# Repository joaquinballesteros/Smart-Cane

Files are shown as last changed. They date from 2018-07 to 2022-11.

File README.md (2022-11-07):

# Smart Cane


Smart-cane is an open hardware and open software project created to promoting an active ageing. This project was created on [Integrated Systems Engineering group](www.grupoisis.uma.es/), on Department of Electronic Technology (Málaga University). Nowadays, it is carried out at MDH University at the [Biomedical Engineering group](http://www.es.mdh.se/research-groups/32-Biomedical_Engineering) in collaboration with [Integrated Systems Engineering group](www.grupoisis.uma.es/).

The project is led by [Dr. Ballesteros](https://www.researchgate.net/profile/Joaquin_Ballesteros) and it counts with the help of [M.Sc. Alberto Tudela](https://duma.uma.es/duma/buscador/persona/535571bb-1da1-4cbd-a49a-7b0d61c4cd2d/), [B.Sc. Juan Caro](https://duma.uma.es/duma/buscador/persona/6eeb9474-2ce9-4c46-8f6d-ff7827abb2c9/) and the support of [Prof. Dr. Maria Lindén](http://www.es.mdh.se/staff/114-Maria_Lind__n) and [Prof. Dr. Cristina Urdiales](https://www.researchgate.net/profile/Cristina_Urdiales2).

This project is focused on adding on-board sensors to the cane to monitor users. These sensors should be affordable in order to reduce the cost and to increase the number of end users. Force sensors and hall effect sensors are being testing to measure the weight-bearing and other significant parameters related with an active ageing. The results are been validated in collaboration with the following Senior centres (Centros de participación activa) in Córdoba (Spain): CÓRDOBA II, FUENSANTA – CAÑERO, PONIENTE, LOS NARANJOS.

## Built With
* [Fusion 360](https://www.autodesk.com/products/fusion-360/overview) - The program used to to design the plastic pieces. All these documents have been exported to STEP file extension too. It is an ISO standard exchange format that can be openned by other programs, such as [FreeCAD](https://github.com/FreeCAD/FreeCAD).

* [MBED online compiler](https://os.mbed.com/handbook/mbed-Compiler) - The online program used to to programming the BLE Nano v1 microcontroller. 

* [Android Studio](https://developer.android.com/studio/) - The program to create the mobile software.

## Authors

* **Joaquín Ballesteros** - *Team leader, design and programming* - [joaquinballesteros](https://github.com/joaquinballesteros)
* **Alberto Tudela** - *Electronic and 3D models* - [ajtudela](https://github.com/ajtudela)
* **Juan Caro** - *Electronic and software* - [jrcaro](https://github.com/jrcaro)

Contact: jballesteros@uma.es

## Contributors

* Swedish Knowledge Foundation (KKS) through the research profile [Embedded Sensor Systems for Health at Mälardalen University](https://www.mdh.se/forskning/inriktningar/inbyggda-system/ess-h?l=en_UK), Sweden - [Prof. Dr. Maria Lindén](http://www.es.mdh.se/staff/114-Maria_Lind__n).

* [Plan Propio de la Universidad de Málaga (Proyectos Puente)](https://www.uma.es/servicio-de-investigacion/cms/menu/plan-propio-de-investigacion/?set_language=en) at Málaga University, Spain -  [Prof. Dr. Cristina Urdiales](https://www.researchgate.net/profile/Cristina_Urdiales2).

## License

This project is licensed under the Creative Commons Attribution 4.0 - see the [LICENSE.md](https://github.com/joaquinballesteros/Smart-Cane/blob/master/LICENSE) file for details.

## Acknowledgments

The authors would like to thank to [Ms. Luna Ruiz](http://lunakageyama.blogspot.com/) who greatly assisted every single test.

## Publications
Ballesteros, J., Tudela, A., Caro-Romero, J. R., & Urdiales, C. (2019). Weight-bearing estimation for cane users by using onboard sensors. Sensors, 19(3), 509. [link](https://www.mdpi.com/1424-8220/19/3/509/htm)

Ballesteros, J., Tudela, A., Caro-Romero, J. R., & Urdiales, C. (2019, May). A cane-based low cost sensor to implement attention mechanisms in telecare robots. In 2019 International Conference on Robotics and Automation (ICRA) (pp. 1473-1478). IEEE.[link](https://ieeexplore.ieee.org/document/8794283)

Caro-Romero, J. R., Ballesteros, J., Garcia-Lagos, F., Urdiales, C., & Sandoval, F. (2019, June). A Neural Network for Stance Phase detection in smart cane users. In International Work-Conference on Artificial Neural Networks (pp. 310-321). Springer, Cham.[link](https://link.springer.com/chapter/10.1007/978-3-030-20521-8_26)

Ayala, I., Ballesteros, J., Caro-Romero, J. R., Amor, M., & Fuentes, L. (2019). Self-Adaptation of mHealth Devices: The Case of the Smart Cane Platform. In Multidisciplinary Digital Publishing Institute Proceedings (Vol. 31, No. 1, p. 23).[link](https://www.mdpi.com/2504-3900/31/1/23)

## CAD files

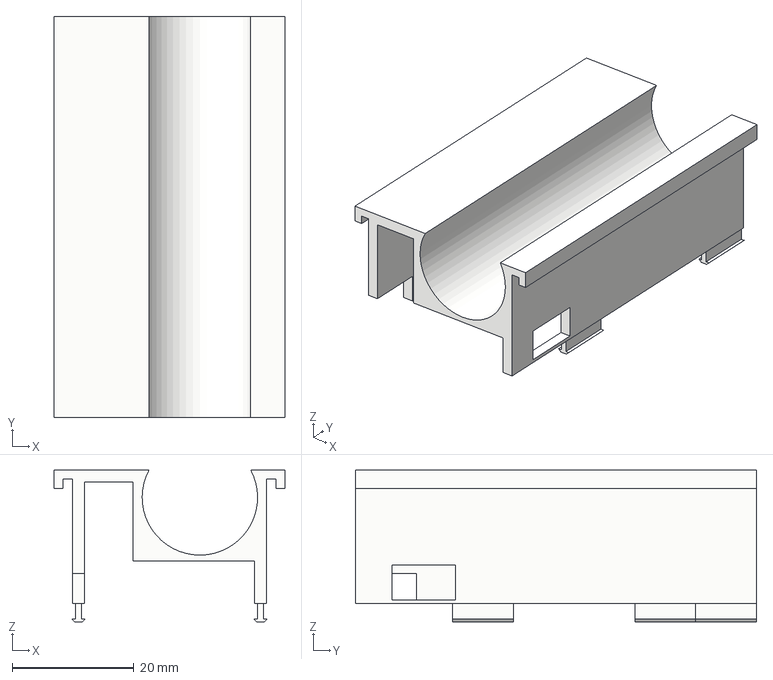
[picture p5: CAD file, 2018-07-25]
CAD/Battery Case/Battery.step
38.0 x 66.0 x 25.0 mm

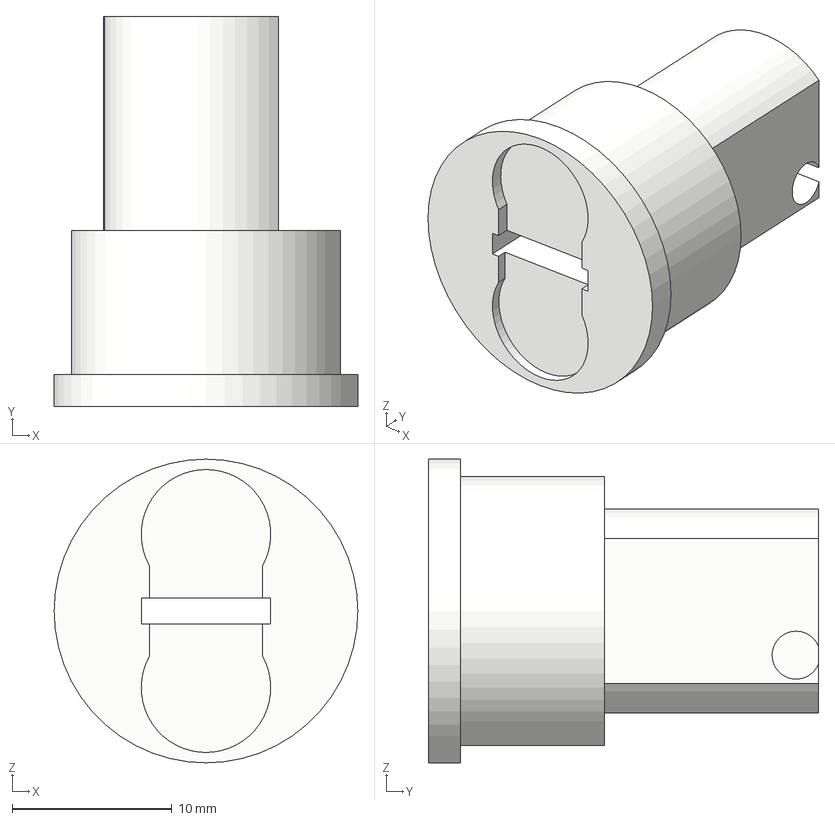
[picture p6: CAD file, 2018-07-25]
CAD/Electronic Case/Interior Sensors.step
19.0 x 24.4 x 19.0 mm

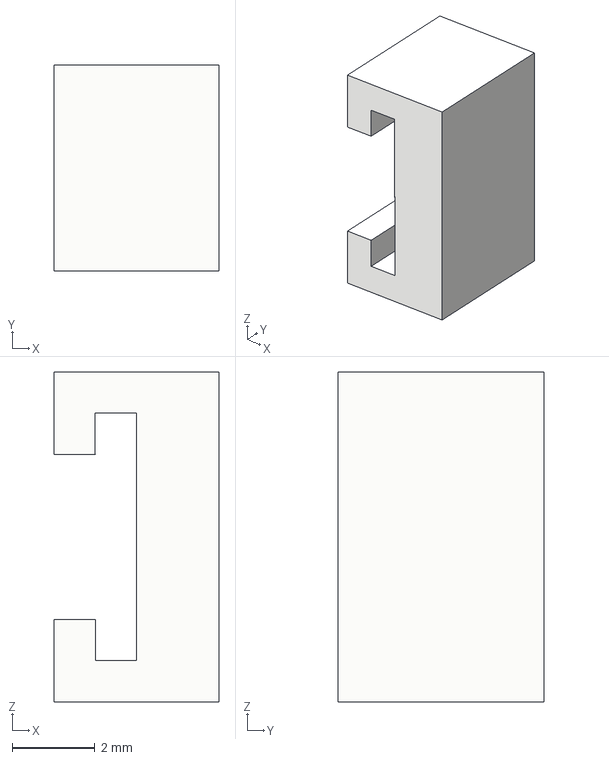
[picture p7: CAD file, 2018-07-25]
CAD/MCU Case/Coupling.step
4.00 x 5.00 x 8.00 mm

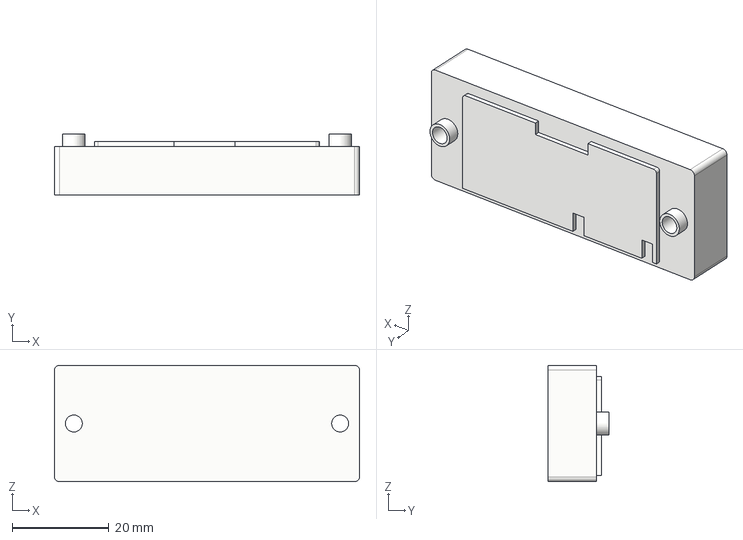
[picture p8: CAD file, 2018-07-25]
CAD/Wall Case/PCB Top.step
63.0 x 12.5 x 24.0 mm

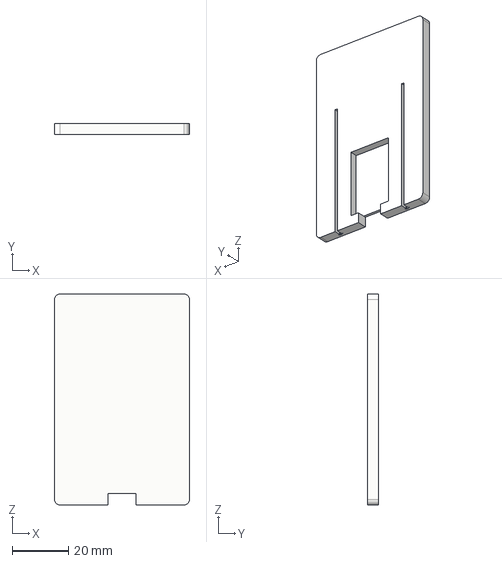
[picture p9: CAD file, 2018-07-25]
CAD/Battery Case/Charger.step
48.0 x 4.00 x 75.0 mm

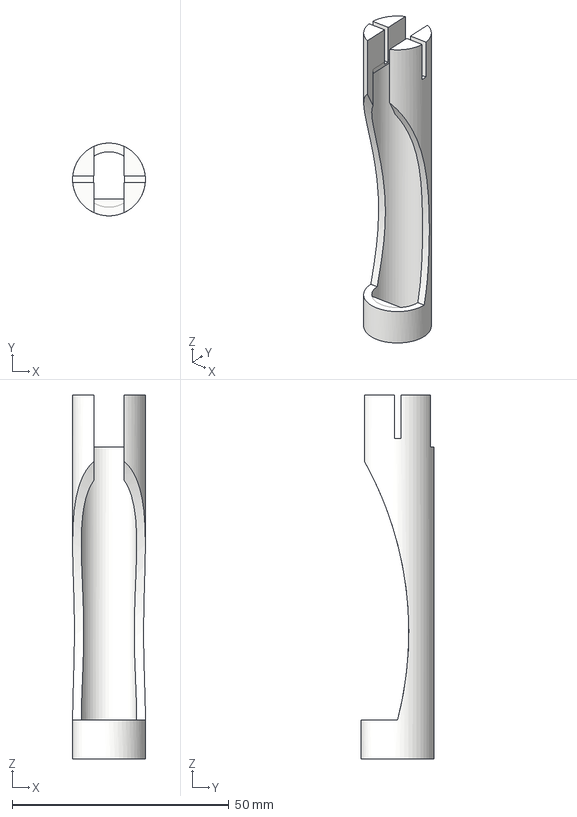
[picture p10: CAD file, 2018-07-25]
CAD/Electronic Case/Board Case.step
16.8 x 16.8 x 84.0 mm

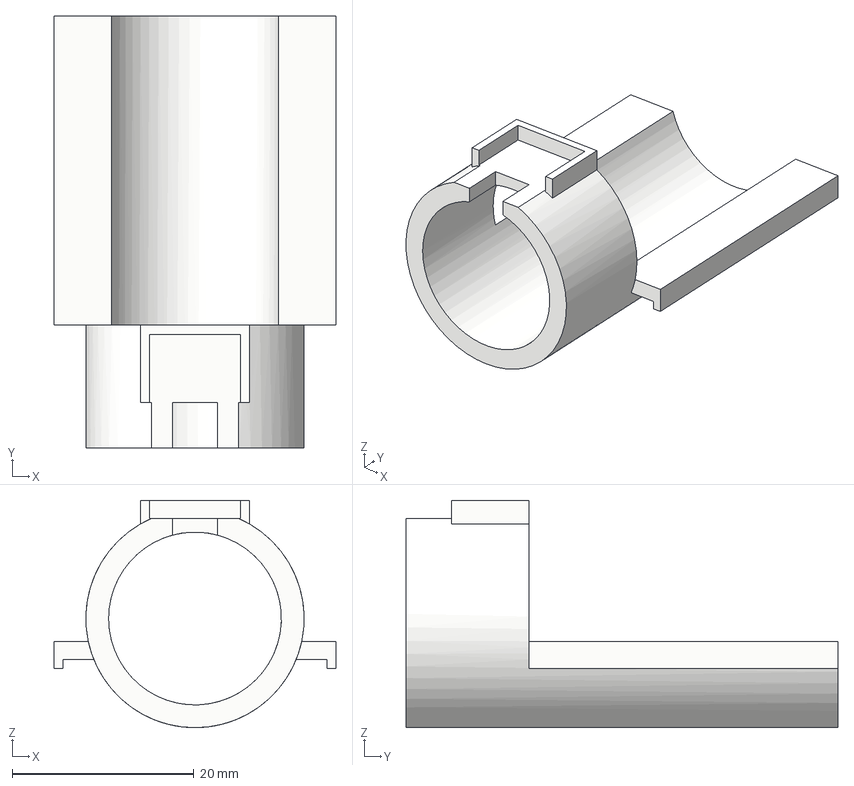
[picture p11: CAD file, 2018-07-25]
CAD/MCU Case/ConectorCase.step
31.0 x 47.5 x 25.0 mm

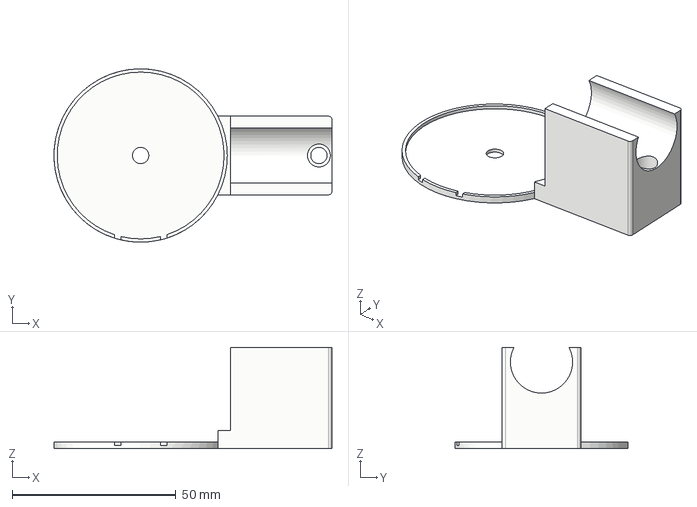
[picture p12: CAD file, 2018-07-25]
CAD/Wall Case/Coil Case.step
85.0 x 53.0 x 31.0 mm

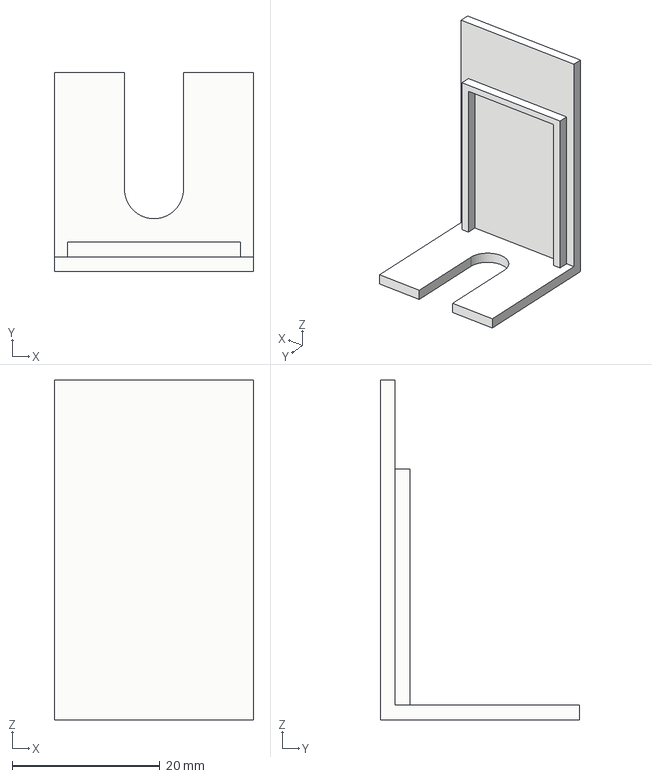
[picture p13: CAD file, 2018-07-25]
CAD/MCU Case/Top.step
27.0 x 27.0 x 46.1 mm

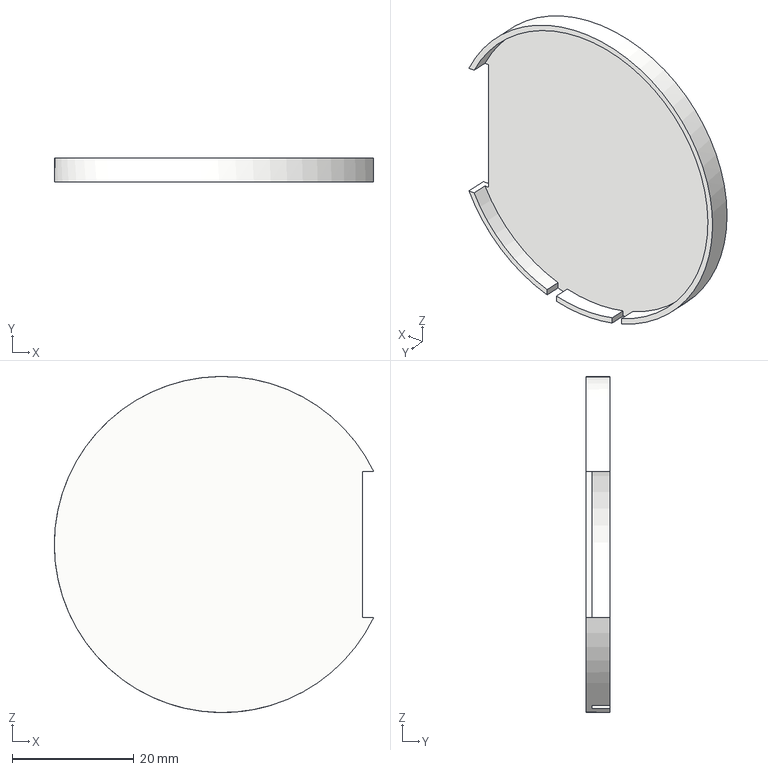
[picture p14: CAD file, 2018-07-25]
CAD/Wall Case/Coil Top.step
52.4 x 4.00 x 55.1 mm

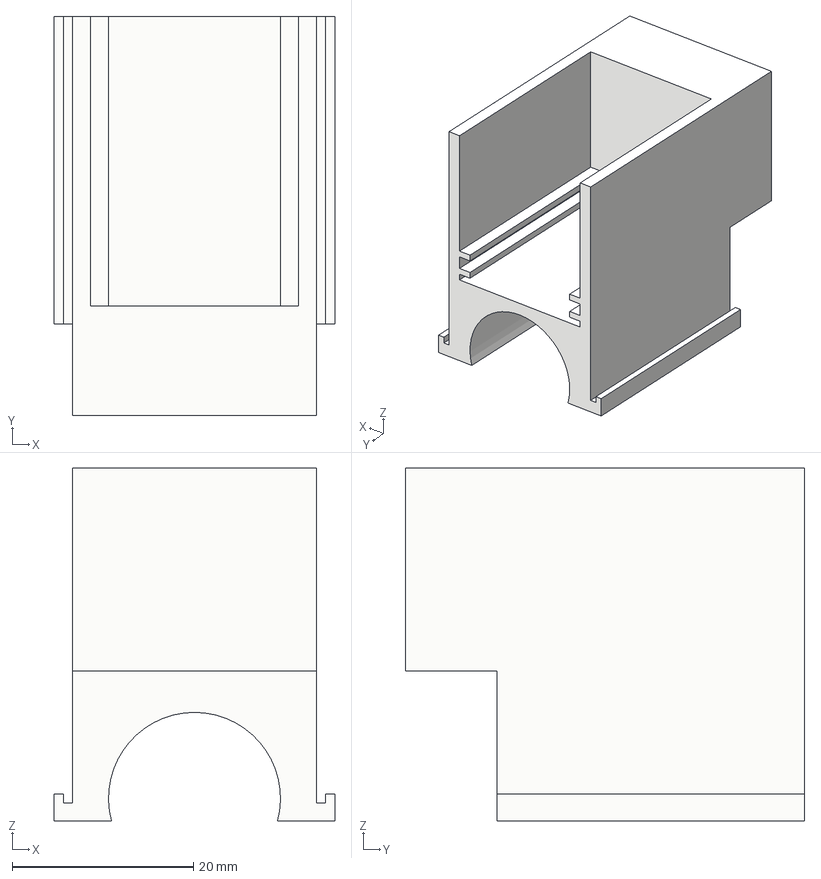
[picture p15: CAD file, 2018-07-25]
CAD/MCU Case/Case.step
31.0 x 44.1 x 39.0 mm

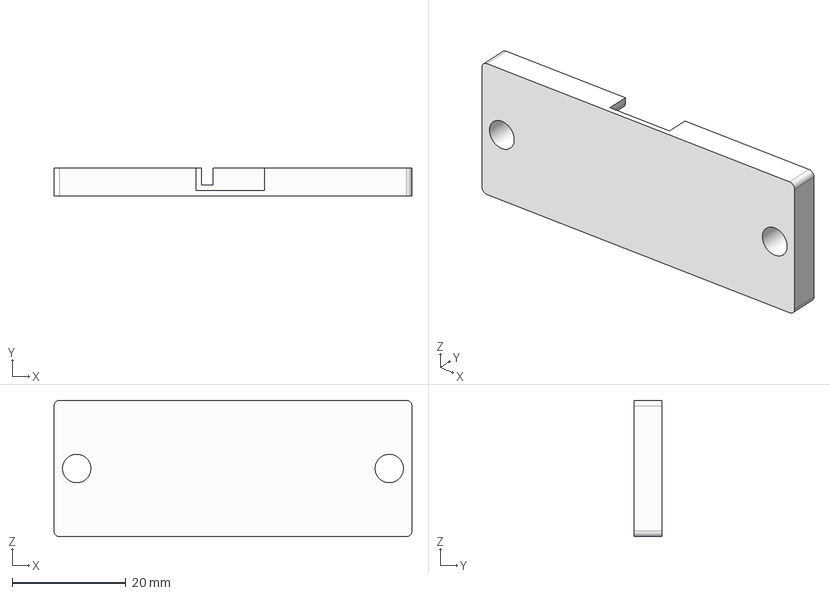
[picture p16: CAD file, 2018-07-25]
CAD/Wall Case/PCB Bottom.step
63.0 x 5.00 x 24.0 mm

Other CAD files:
CAD/Battery Case/Battery Case v1.f3d
CAD/Electronic Case/Electronic Case v1.f3d
CAD/MCU Case/MCU Case v1.f3d
CAD/Sensor Board.f3d
CAD/Wall Case/Wall Case v1.f3d

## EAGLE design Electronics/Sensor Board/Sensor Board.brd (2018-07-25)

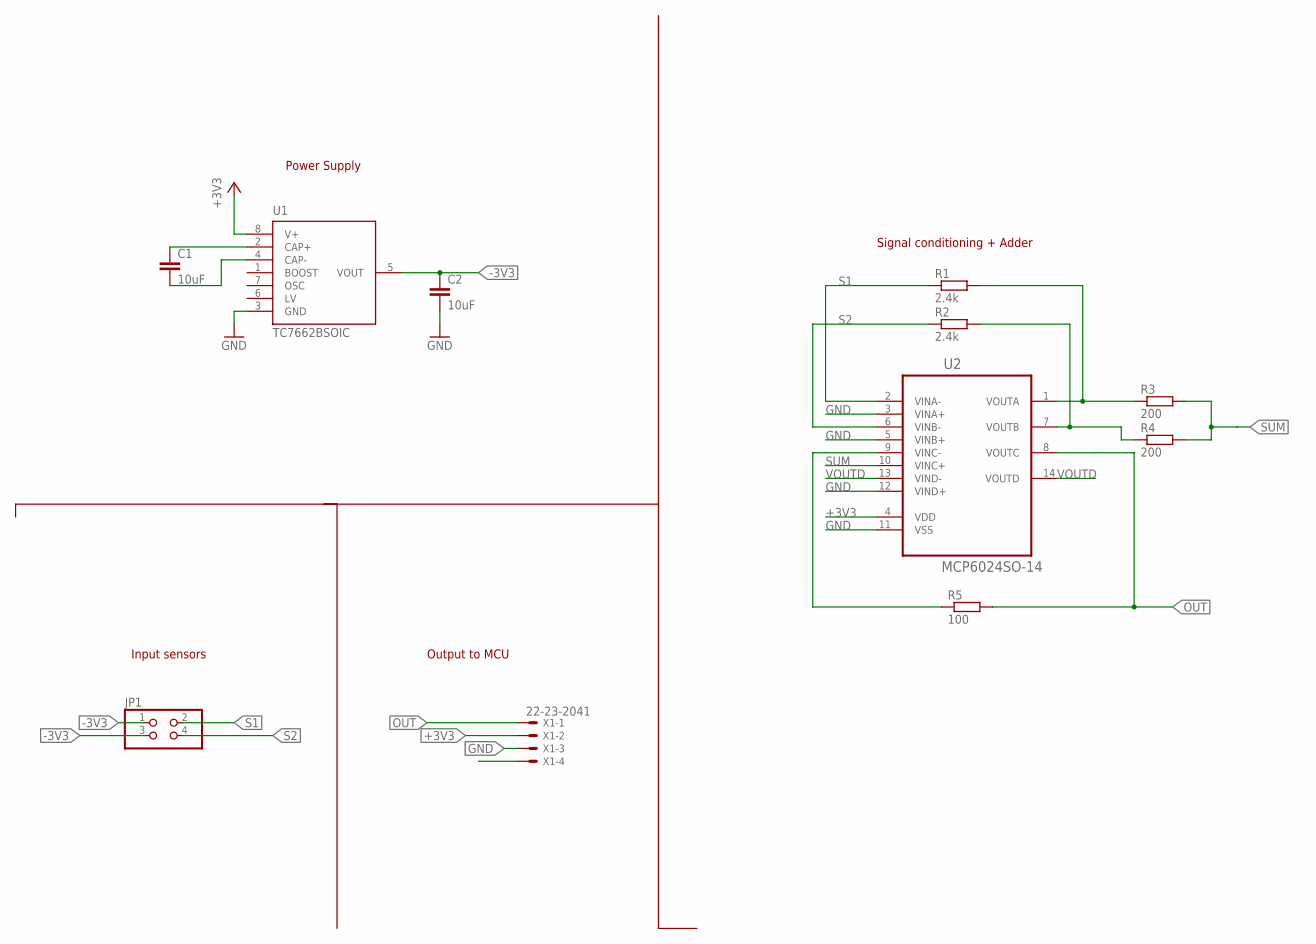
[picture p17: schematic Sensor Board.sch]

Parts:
C1, C2: 10uF; C0603
JP1: PINHD-2X2/90; 2X02/90
R1, R2: 2.4k; R0603
R3, R4: 200; R0603
R5: 100; R0603
U1: TC7662BSOIC; SO-08
U2: MCP6024SO-14; SO-14
X1: 22-23-2041

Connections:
+3V3: U1.8 (V+), U2.4 (VDD), X1.2
-3V3: C2.1, JP1.1, JP1.3, U1.5 (VOUT)
GND: C2.2, U1.3 (GND), U2.3 (VINA+), U2.5 (VINB+), U2.11 (VSS), U2.12 (VIND+), X1.3
unnamed: C1.1, U1.2 (CAP+)
unnamed: C1.2, U1.4 (CAP-)
unnamed: R1.2, R3.1, U2.1 (VOUTA)
unnamed: R2.2, R4.1, U2.7 (VOUTB)
unnamed: R5.1, U2.9 (VINC-)
OUT: R5.2, U2.8 (VOUTC), X1.1
S1: JP1.2, R1.1, U2.2 (VINA-)
S2: JP1.4, R2.1, U2.6 (VINB-)
SUM: R3.2, R4.2, U2.10 (VINC+)
VOUTD: U2.13 (VIND-), U2.14 (VOUTD)

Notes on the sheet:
Power Supply
Signal conditioning + Adder
Input sensors
Output to MCU

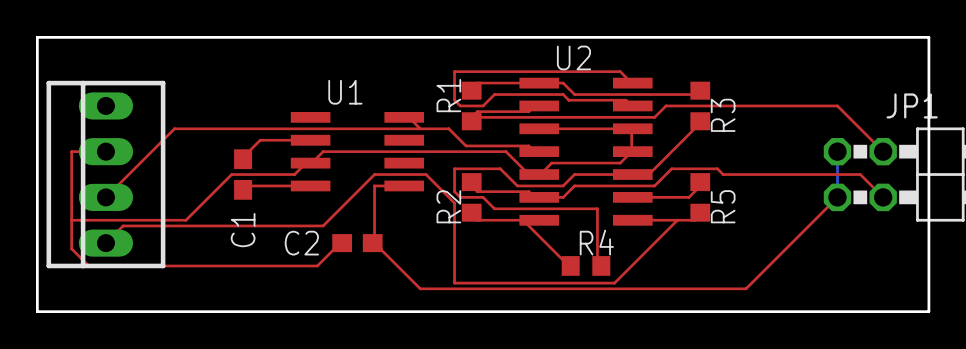
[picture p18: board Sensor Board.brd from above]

Board: 2 copper layers, 49.5 x 15.2 mm, 11 parts (0 on the bottom side), 13 nets.

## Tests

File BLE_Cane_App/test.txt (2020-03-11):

Escrito en remoto linea 1
Escrito en remoto linea 2
Escrito en remoto linea 3
Escrito en remoto linea 4
Escrito en remoto linea 5

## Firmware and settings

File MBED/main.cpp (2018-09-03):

#include "mbed.h"
#include "ble/BLE.h"
#include "ble/services/UARTService.h"
#include <string>
#include <vector>

//------------------------------------------------------------
// Definition
//------------------------------------------------------------
#define TAM                    400 //multiplos de 20
#define TICKER_INSERT          0.02 //50 Hz
#define TICKER_SEND            8*TICKER_INSERT //nunca mayor que 10
#define MIN_CONN_INTERVAL      TICKER_SEND*1000/2 //250 milliseconds
#define MAX_CONN_INTERVAL      TICKER_SEND*1000 //350 milliseconds

//------------------------------------------------------------
// Object generation
//------------------------------------------------------------
BLEDevice       ble;
Ticker          ticker_insert;
Ticker          ticker_send;
Timer           tPasos;
Timer           tActividad;
UARTService     *uartServicePtr;
AnalogIn        forceSensor(P0_4);

//------------------------------------------------------------
// Activity variables
//------------------------------------------------------------
static const uint16_t BEGIN_LRM_AFTER = 4; //Tiempo para pasar a inactividad
static const uint16_t IDLE_FORCE_SENSOR_THRESHOLD = 15; //Threshold lectura minima sensor
static const float MINIMUN_STEP = 0.3; //Tiempo minimo para que un paso sea valido
uint32_t readForceIdleCounter = 0; // init the idle counter to 0
static const int offset = 0; //error en ms entre movil y video

struct Estados { //Maquina de estados
    //I_State->1, S*_State->2, S_State->3, NS*_State->4, NS_State->5
    uint16_t Anterior;
    uint16_t Actual;
    bool PSoporte;
    bool Soporte;
} State;

struct Activity {
    uint32_t actLength;
    uint16_t data_act[7];
    bool fail;
};

static uint16_t fsrReading = 0;
uint32_t actLen;
uint32_t act_cont = 0;
bool requestAct, sync_act, chgCont;
uint8_t rx_buf[20];

vector<uint16_t> S_Matrix;
vector<uint16_t> NS_Matrix;
vector<Activity> act_buffer;

//------------------------------------------------------------
// Raw variables
//------------------------------------------------------------
uint8_t circularBuffer[TAM];
uint16_t i = 0;
uint16_t e = 0;
uint16_t j = 0;
bool sync_raw;

/**
    Raw Data functions: Modular Addition, Modular Subtraction
**/

//======================================================================
// Modular Addition
//======================================================================
uint16_t modularAdd(uint16_t x, uint16_t y, uint16_t tam)
{
    return ((x+y) % tam);
}

//======================================================================
// Modular Subtraction
//======================================================================
uint16_t modularSub(uint16_t x, uint16_t y, uint16_t tam)
{
    return (((x>y?x:x+tam)-y) % tam);
}

/**
    Activity functions: Measurement, StateMachine
**/

//======================================================================
// Measurement
//======================================================================
int MeasurementFunction(const vector<uint16_t> &X, const vector<uint16_t> &Y)
{
    int temp, len;
    float meanS, meanNS, sim, varS, varNS;
    Activity tempAct;

    if ((X.size() != 0) && (Y.size() != 0)) {
        temp = X.size() + Y.size();

        meanS = 0;
        meanNS = 0;
        varS = 0;
        varNS = 0;
        if (X.size() >= Y.size()) {
            len = Y.size();
        } else {
            len = X.size();
        }
        for (int k = 1; k < (len-1); k++) {
            meanS += X[k]; //acumula el tiempo de los pasos de soporte en una variable
            meanNS += Y[k]; //acumula el tiempo de los pasos de no soporte en una variable
        }
        if(len > 2) {

            meanS /= (len-2)*1.0; //media aritmetica (ms)
            meanNS /= (len-2)*1.0;

            for(int n = 1; n < (len-1); n++ ) {
                varS += ((X[n]) - (meanS)) * ((X[n]) - (meanS));
                varNS += ((Y[n]) - (meanNS)) * ((Y[n]) - (meanNS));
            }

            varS /= ((len-2)*1.0); //varianza (ms)
            varNS /=  ((len-2)*1.0);

            sim = meanNS / meanS;

            tempAct.data_act[0] = temp; //pasos
            if (actLen != 0) {
                tempAct.actLength = (actLen/1000.0)*1000; //duracion de la actividad (segundos)*1000
                tempAct.data_act[1] = (temp / (actLen*1.0)) * 60 * 1000 * 100; //cadencia *100
                tempAct.data_act[2] = meanS; //media temporal de los pasos de soporte
                tempAct.data_act[3] = meanNS; //media temporal de los pasos de no soporte
                tempAct.data_act[4] = sim * 1000; //simetria de los pasos ()*1000
                tempAct.data_act[5] = varS * 100; //varianza
                tempAct.data_act[6] = varNS * 100; //varianza
            } else {
                tempAct.fail = true;
                act_buffer.push_back(tempAct);
                return 3;
            }
        } else {
            tempAct.fail = true;
            act_buffer.push_back(tempAct);
            return 2;
        }
    } else {
        tempAct.fail = true;
        act_buffer.push_back(tempAct);
        return 1;
    }
    tempAct.fail = false;
    act_buffer.push_back(tempAct);
    return 0;
}

//======================================================================
// State Machine Process
//======================================================================
void stateMachine()
{
    //Reading data
    if (fsrReading > IDLE_FORCE_SENSOR_THRESHOLD) {
        State.Soporte = true;
    } else {
        State.Soporte = false;
    }

    //Estimating the actual state
    switch (State.Anterior) {
        case 1:
            if (State.PSoporte != State.Soporte) {
                tPasos.reset();
                if (State.Soporte) {
                    State.Actual = 2;
                } else {
                    State.Actual = 4;
                }
            } else {
                State.Actual = 1;
            }
            break;
        case 2:
            if ((readForceIdleCounter * TICKER_INSERT >= BEGIN_LRM_AFTER) || ((readForceIdleCounter * TICKER_INSERT < MINIMUN_STEP) && !(State.Soporte))) {
                State.Actual = 1;
            } else if ((readForceIdleCounter * TICKER_INSERT > MINIMUN_STEP) && !(State.Soporte)) {
                State.Actual = 3;
            } else {
                State.Actual = 2;
            }
            break;
        case 3:
            State.Actual = 4;
            break;
        case 4:
            if ((readForceIdleCounter * TICKER_INSERT >= BEGIN_LRM_AFTER) || ((readForceIdleCounter * TICKER_INSERT < MINIMUN_STEP) && (State.Soporte))) {
                State.Actual = 1;
            } else if ((readForceIdleCounter * TICKER_INSERT > MINIMUN_STEP) && (State.Soporte)) {
                State.Actual = 5;
            } else {
                State.Actual = 4;
            }
            break;
        case 5:
            State.Actual = 2;
            break;
    }

    //State's actions
    switch (State.Actual) {
        case 1:
            readForceIdleCounter = 0;
            if (((State.Anterior == 2) || (State.Anterior == 4)) && ((S_Matrix.size() != 0) && (NS_Matrix.size() != 0))) {
                actLen = tActividad.read_ms() - (BEGIN_LRM_AFTER * 1000); //compensar los 200 datos para volver a estado 1 estando en 2-4
                MeasurementFunction(S_Matrix, NS_Matrix);
                act_cont++;
                chgCont = true;
                S_Matrix.clear();
                NS_Matrix.clear();
                tActividad.reset();
            }
            break;
        case 2:
            readForceIdleCounter++;
            break;
        case 3:
            S_Matrix.push_back(tPasos.read_ms() + offset);
            tPasos.reset();
            readForceIdleCounter = 0;
            break;
        case 4:
            readForceIdleCounter++;
            break;
        case 5:
            NS_Matrix.push_back(tPasos.read_ms() - offset);
            tPasos.reset();
            readForceIdleCounter = 0;
            break;
    }

    State.Anterior = State.Actual;
    State.PSoporte = State.Soporte;

}

/**
    Common functions: insertCallback, disconnectionCallback, sendCallback, syncTime
**/

//======================================================================
// Callback Send
//======================================================================
void sendCallback()
{
    if(sync_raw){
        if (ble.getGapState().connected && modularSub(i,e,TAM) >= 20) {
            ble.updateCharacteristicValue(uartServicePtr->getRXCharacteristicHandle(), &circularBuffer[e], 20);
            e = modularAdd(e,20,TAM);
        }
    }
    
    if (ble.getGapState().connected) {
        if(act_cont != 0 && chgCont) {
            rx_buf[0] = (act_cont >> 24);
            rx_buf[1] = (act_cont >> 16);
            rx_buf[2] = (act_cont >> 8);
            rx_buf[3] = act_cont;
            ble.updateCharacteristicValue(uartServicePtr->getRXCharacteristicHandle(), rx_buf, 4);
            chgCont = false;
        } else if(requestAct && !act_buffer.empty() && !act_buffer.front().fail) {
            rx_buf[0] = (act_buffer.front().actLength >> 24);
            rx_buf[1] = (act_buffer.front().actLength >> 16);
            rx_buf[2] = (act_buffer.front().actLength >> 8);
            rx_buf[3] = act_buffer.front().actLength;
            rx_buf[4] = (act_buffer.front().data_act[0] >> 8);
            rx_buf[5] = act_buffer.front().data_act[0];
            rx_buf[6] = (act_buffer.front().data_act[1] >> 8);
            rx_buf[7] = act_buffer.front().data_act[1];
            rx_buf[8] = (act_buffer.front().data_act[2] >> 8);
            rx_buf[9] = act_buffer.front().data_act[2];
            rx_buf[10] = (act_buffer.front().data_act[3] >> 8);
            rx_buf[11] = act_buffer.front().data_act[3];
            rx_buf[12] = (act_buffer.front().data_act[4] >> 8);
            rx_buf[13] = act_buffer.front().data_act[4];
            rx_buf[14] = (act_buffer.front().data_act[5] >> 8);
            rx_buf[15] = act_buffer.front().data_act[5];
            rx_buf[16] = (act_buffer.front().data_act[6] >> 8);
            rx_buf[17] = act_buffer.front().data_act[6];
            ble.updateCharacteristicValue(uartServicePtr->getRXCharacteristicHandle(), rx_buf, 18);
            act_buffer.erase(act_buffer.begin());
            if(act_buffer.empty()) requestAct = false;
        }
    }
}

//======================================================================
// Read sensor callback
//======================================================================
void insertCallback()
{
    if(sync_act) {
        fsrReading = forceSensor.read_u16();
        stateMachine();
    }
    
    if(sync_raw){
        fsrReading = forceSensor.read_u16();
        if (i != modularSub(e,2,TAM)) {
            circularBuffer[i] = (fsrReading >> 8); //MSB
            circularBuffer[i+1] = fsrReading; //LSB
            i = modularAdd(i,2,TAM);
            j=0;
        } else {
            circularBuffer[i] = ((65536-j) >> 8); //MSB
            circularBuffer[i+1] = (65536-j); //LSB
            j++;
            i = i;
        }
    }
}

//======================================================================
// onDisconnection
//======================================================================
void disconnectionCallback(const Gap::DisconnectionCallbackParams_t *params)
{
    if(sync_act){
        requestAct = true;
        act_cont = 0;
        sync_act = false;
        tPasos.stop();
        tActividad.stop();
    }
    ble.startAdvertising();
}

//======================================================================
// Data Written Callback
//======================================================================
void syncTime(const GattWriteCallbackParams *params)
{
    if ((uartServicePtr != NULL) && (params->handle == uartServicePtr->getTXCharacteristicHandle())) {
        if(params->data[0] == 0x30){
            sync_raw = true;
            insertCallback();
        } else if(params->data[0] == 0x31) {
            tPasos.start();
            tActividad.start();
            sync_act = true;
            requestAct = false;
        } else if(params->data[0] == 0x32) {
            requestAct = true;
            act_cont = 0;
            sync_act = false;
            tPasos.stop();
            tActividad.stop();
        }
        ticker_insert.attach(insertCallback, TICKER_INSERT);
        ticker_send.attach(sendCallback, TICKER_SEND);
    }
}

//======================================================================
// Main
//======================================================================
int main(void)
{

    fsrReading = forceSensor.read_u16();

    if (fsrReading > IDLE_FORCE_SENSOR_THRESHOLD) {
        State.PSoporte = true;
    } else {
        State.PSoporte = false;
    }

    State.Soporte = false;
    State.Anterior = 1;

    ble.init();
    ble.onDisconnection(disconnectionCallback);
    ble.onDataWritten(syncTime);

    /* setup advertising */
    ble.accumulateAdvertisingPayload(GapAdvertisingData::BREDR_NOT_SUPPORTED);
    ble.setAdvertisingType(GapAdvertisingParams::ADV_CONNECTABLE_UNDIRECTED);
    ble.accumulateAdvertisingPayload(GapAdvertisingData::SHORTENED_LOCAL_NAME,
                                     (const uint8_t *)"BLE Cane", sizeof("BLE Cane") - 1);
    ble.accumulateAdvertisingPayload(GapAdvertisingData::COMPLETE_LIST_128BIT_SERVICE_IDS,
                                     (const uint8_t *)UARTServiceUUID_reversed, sizeof(UARTServiceUUID_reversed));

    ble.setAdvertisingInterval(1000); /* 1000ms; in multiples of 0.625ms. */
    ble.startAdvertising();

    UARTService uartService(ble);
    uartServicePtr = &uartService;
    sync_raw = false;
    sync_act = false;

    do {
        ble.waitForEvent();
    } while(!ble.getGapState().connected);

    while (true) {
        ble.waitForEvent();
    }
}

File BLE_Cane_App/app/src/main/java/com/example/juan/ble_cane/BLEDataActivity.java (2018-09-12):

/*
 * Copyright (c) 2015, Nordic Semiconductor
 * All rights reserved.
 *
 * Redistribution and use in source and binary forms, with or without modification, are permitted provided that the following conditions are met:
 *
 * 1. Redistributions of source code must retain the above copyright notice, this list of conditions and the following disclaimer.
 *
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
 * 3. Neither the name of the copyright holder nor the names of its contributors may be used to endorse or promote products derived from this
 * software without specific prior written permission.
 *
 * THIS SOFTWARE IS PROVIDED BY THE COPYRIGHT HOLDERS AND CONTRIBUTORS "AS IS" AND ANY EXPRESS OR IMPLIED WARRANTIES, INCLUDING, BUT NOT
 * LIMITED TO, THE IMPLIED WARRANTIES OF MERCHANTABILITY AND FITNESS FOR A PARTICULAR PURPOSE ARE DISCLAIMED. IN NO EVENT SHALL THE COPYRIGHT
 * HOLDER OR CONTRIBUTORS BE LIABLE FOR ANY DIRECT, INDIRECT, INCIDENTAL, SPECIAL, EXEMPLARY, OR CONSEQUENTIAL DAMAGES (INCLUDING, BUT NOT
 * LIMITED TO, PROCUREMENT OF SUBSTITUTE GOODS OR SERVICES; LOSS OF USE, DATA, OR PROFITS; OR BUSINESS INTERRUPTION) HOWEVER CAUSED AND ON
 * ANY THEORY OF LIABILITY, WHETHER IN CONTRACT, STRICT LIABILITY, OR TORT (INCLUDING NEGLIGENCE OR OTHERWISE) ARISING IN ANY WAY OUT OF THE
 * USE OF THIS SOFTWARE, EVEN IF ADVISED OF THE POSSIBILITY OF SUCH DAMAGE.
 */
package com.example.juan.ble_cane;

import java.io.File;
import java.io.FileOutputStream;
import java.io.IOException;
import java.io.OutputStream;
import java.io.UnsupportedEncodingException;
import java.nio.ByteBuffer;
import java.text.DateFormat;
import java.text.SimpleDateFormat;
import java.util.Arrays;
import java.util.Date;

import android.app.Activity;
import android.app.AlertDialog;
import android.bluetooth.BluetoothAdapter;
import android.bluetooth.BluetoothDevice;

import android.content.BroadcastReceiver;
import android.content.ComponentName;
import android.content.Context;
import android.content.DialogInterface;
import android.content.Intent;
import android.content.IntentFilter;
import android.content.ServiceConnection;
import android.content.res.Configuration;
import android.os.Bundle;
import android.os.Environment;
import android.os.Handler;
import android.os.IBinder;
import android.os.Message;
import android.support.v4.content.LocalBroadcastManager;
import android.support.v7.app.AppCompatActivity;
import android.support.v7.widget.Toolbar;
import android.util.Log;
import android.view.View;
import android.widget.Button;
import android.widget.RadioGroup;
import android.widget.TextView;
import android.widget.Toast;

import static java.lang.StrictMath.sqrt;

public class BLEDataActivity extends AppCompatActivity implements RadioGroup.OnCheckedChangeListener {
    private static final int REQUEST_SELECT_DEVICE = 1;
    private static final int REQUEST_ENABLE_BT = 2;
    private static final int UART_PROFILE_READY = 10;
    public static final String TAG = "nRFUART";
    private static final int UART_PROFILE_CONNECTED = 20;
    private static final int UART_PROFILE_DISCONNECTED = 21;
    private static final int STATE_OFF = 10;

    TextView mRemoteRssiVal;
    RadioGroup mRg;
    private int mState = UART_PROFILE_DISCONNECTED;
    private UartService mService = null;
    private BluetoothDevice mDevice = null;
    private BluetoothAdapter mBtAdapter = null;
    private TextView textView;
    private Button btnConnectDisconnect,btnSend, btnRequest;
    String fullPath = Environment.getExternalStorageDirectory().getAbsolutePath() + "/Cane";
    boolean btnSelect; //boton sync(true) o request(false)
    long epoch;
    int counter;

    @Override
    public void onCreate(Bundle savedInstanceState) {
        super.onCreate(savedInstanceState);
        setContentView(R.layout.activity_bledata);

        Toolbar toolbar = (Toolbar) findViewById(R.id.toolbar);
        setSupportActionBar(toolbar);

        mBtAdapter = BluetoothAdapter.getDefaultAdapter();
        if (mBtAdapter == null) {
            Toast.makeText(this, "Bluetooth is not available", Toast.LENGTH_LONG).show();
            finish();
            return;
        }
        textView = (TextView)findViewById(R.id.textView);
        btnConnectDisconnect=(Button) findViewById(R.id.btn_select);
        btnSend=(Button) findViewById(R.id.sendButton);
        btnRequest=(Button) findViewById(R.id.requestButton);
        service_init();

        // Handle Disconnect & Connect button
        btnConnectDisconnect.setOnClickListener(new View.OnClickListener() {
            @Override
            public void onClick(View v) {
                if (!mBtAdapter.isEnabled()) {
                    Log.i(TAG, "onClick - BT not enabled yet");
                    Intent enableIntent = new Intent(BluetoothAdapter.ACTION_REQUEST_ENABLE);
                    startActivityForResult(enableIntent, REQUEST_ENABLE_BT);
                }
                else {
                    if (btnConnectDisconnect.getText().equals("Connect")){
                        //Connect button pressed, open DeviceListActivity class, with popup windows that scan for devices
                        Intent newIntent = new Intent(BLEDataActivity.this, DeviceListActivity.class);
                        startActivityForResult(newIntent, REQUEST_SELECT_DEVICE);
                    } else {
                        //Disconnect button pressed
                        if (mDevice!=null)
                        {
                            mService.disconnect();

                        }
                    }
                }
            }
        });
        // Handle Send button
        btnSend.setOnClickListener(new View.OnClickListener() {
            @Override
            public void onClick(View v) {
                epoch = System.currentTimeMillis();
                Date date = new Date(epoch);
                SimpleDateFormat jdf = new SimpleDateFormat("HH:mm:ss:SSS dd-MM-yyyy");
                final String java_date = jdf.format(date);
                final String strIni = java_date + "\n";
                writeToFile(strIni);
                String strInit = "1";
                byte[] value;
                btnSelect = true;
                try {
                    //send data to service
                    value = strInit.getBytes("UTF-8");
                    mService.writeRXCharacteristic(value);
                    //Update the log with time stamp
                    textView.setText("Inicializacion");
                } catch (UnsupportedEncodingException e) {
                    // TODO Auto-generated catch block
                    e.printStackTrace();
                }

            }
        });
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

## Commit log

2018-07-25 Added CAD files
    [Battery Case v1.f3d, Battery.step, Board Case.step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]
2018-07-25 Added schematics and pcb for sensor board
    [Sensor Board.brd, Sensor Board.sch]
2018-07-26 Change in schematics for better reading
    [Sensor Board.sch]

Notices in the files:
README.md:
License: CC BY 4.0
